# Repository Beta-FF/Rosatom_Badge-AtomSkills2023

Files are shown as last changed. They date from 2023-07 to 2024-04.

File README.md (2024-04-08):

# Rosatom Badge
Сувенирный значок с мастер-класса компетенции "Электроника" чемпионата AtomSkills 2023.  
[Ссылка на проект EasyEDA](https://oshwlab.com/treegervd/rosatom_badge_edapro)

Использованные библиотеки:
* [MicroCore](https://github.com/MCUdude/MicroCore) ([MCUdude](https://github.com/MCUdude))
* [ws2812b_attiny13](https://github.com/dsprenkels/ws2812b_attiny13) ([dsprenkels](https://github.com/dsprenkels))

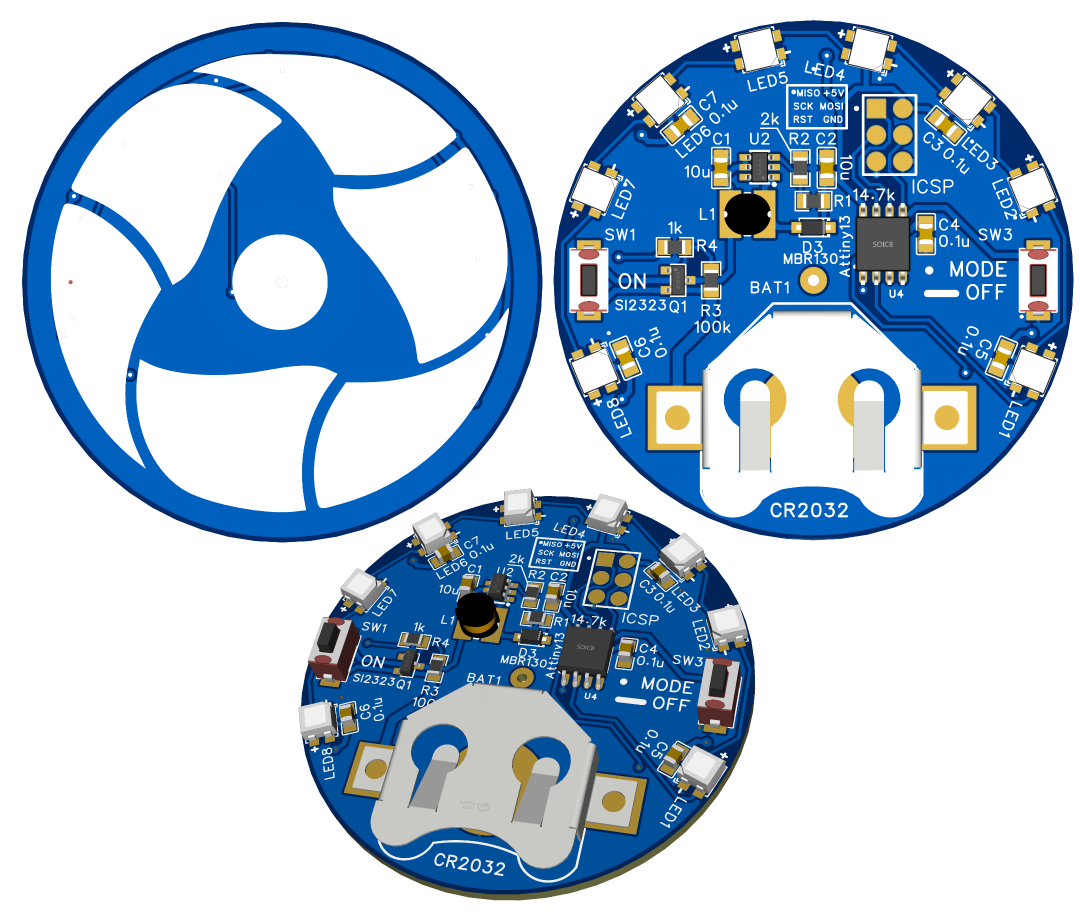
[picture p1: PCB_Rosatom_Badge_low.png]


## Подготовка
* Установить среду [Arduino IDE](https://www.arduino.cc/en/software) и ядро [MicroCore](https://github.com/MCUdude/MicroCore)
* Выбрать в настройках проекта:  
BOD: __BOD 2.7V__  
Bootloader: __No bootloader__  
Clock: __9.6 Mhz internal osc.__  
EEPROM: __EEPROM retained__  
* Если МК новый, то первую прошивку загружать на __slow__ скорости, например __USBasp slow__ (в зависимости от программатора). Дальнейшие загрузки возможны на нормальной скорости (__USBasp__).

## Функционал
Включение значка осуществляется кнопкой __ON__. Кратковременное нажатие кнопки __MODE/OFF__ циклически переключает режимы подсветки, а удержание более 1 сек. выключает значок.  

Режимы подсветки:
* Плавный перелив
* Бегущая точка 
* Статичный белый
* Бегущая радуга

## Техническая документация
[Attiny13 datasheet](http://ww1.microchip.com/downloads/en/DeviceDoc/doc2535.pdf)  
[WS2812B datasheet](https://cdn-shop.adafruit.com/datasheets/WS2812B.pdf)

## Известные баги
* значок не выключается при уровне BOD менее 2.7V. Связано с ошибкой в схеме самоблокировки питания. В выключенном состоянии на затворе Q1 присутствует напряжение ~1.7V, чего хватает для частичного открытия ключа.  
Для исправления нужно добавить еще один N-ch MOSFET или биполярный NPN от затвора Q1 на GND.  
Исправленная схема:  
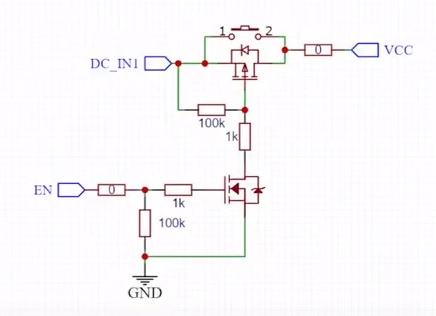
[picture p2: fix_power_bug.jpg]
  
* В редких случаях при установке батареи все светодиоды загораются ярким красным светом. Точная причина не опеределена. Возможно, поможет резистор на 100-500 Ом в разрыв цепи U4_PB3 - LED1_DIN.  
Лечится извлечением и повторной установкой батареи.  

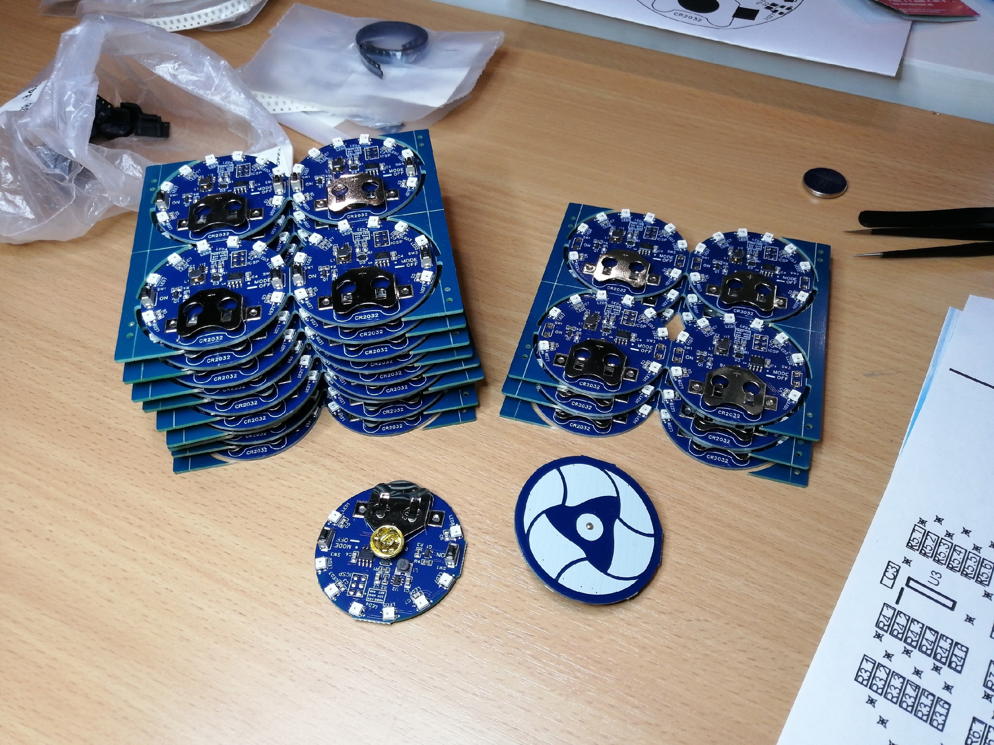
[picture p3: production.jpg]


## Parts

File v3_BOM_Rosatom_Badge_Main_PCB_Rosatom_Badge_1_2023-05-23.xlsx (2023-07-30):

No. | Quantity |  | Comment | Designator | Footprint | Link
1 | 200 | 1 | CR2032 | BAT1 | BAT-SMD_MYOUNG_MY-2032-04 | https://www.promelec.ru/product/340772/ | Замена на другой
2 | 400 | 2 | 10u | C1,C2 | C0805 | https://www.promelec.ru/product/112492/
3 | 1000 | 5 | 0.1u | C3,C4,C5,C6,C7 | C0805 | https://www.promelec.ru/product/124545/
4 | 200 | 1 | Any shottky diode | D3 | SOD-123FL_L2.6-W1.7-LS3.6-RD | https://www.promelec.ru/product/525329/
5 | 200 | 1 | 22u | L1 | IND-SMD_L4.5-W4.0_CD43 | https://www.promelec.ru/product/317110/ | Замена 22u на 10u
6 | 1800 | 9 | WS2812B-Mini | LED1,LED2,LED3,LED4,LED5,LED6,LED7,LED8,LED9 | LED-SMD_4P-L3.5-W3.5-TL_WS2812B | https://www.promelec.ru/product/352874/ | Меняем WS2812C-2020 на WS2812B-Mini
7 | 200 | 1 | SI2323 | Q1 | SOT-23-3_L2.9-W1.3-P1.90-LS2.4-BR | https://www.promelec.ru/product/526695/
8 | 200 | 1 | 14.7k | R1 | R0805 | https://www.promelec.ru/product/304878/
9 | 200 | 1 | 2k | R2 | R0805 | https://www.promelec.ru/product/109734/
10 | 200 | 1 | 100k | R3 | R0805 | https://www.promelec.ru/product/517703/
11 | 200 | 1 | 1k | R4 | R0805 | https://www.promelec.ru/product/517699/
12 | 400 | 2 | Switch SPST Button 0.05A 24VDC 1.77N SMD | SW1,SW2 | SW-SMD_L4.0-W3.0-LS5.0 | https://www.promelec.ru/product/358145/ | Замена на другую
13 | 200 | 1 | ATTINY13 | U4 | SOIC-8_L4.9-W3.9-P1.27-LS6.0-BL-2 | https://www.platan.ru/cgi-bin/qwery.pl/id=2015146753 | Замена ATTINY10 на ATTINY13
14 | 200 | 1 | MT3608 | U2 | SOT-23-6_L2.9-W1.6-P0.95-LS2.8-BR | https://www.chipdip.ru/product0/8020176720
15 | 200 | 1 |  | U3 | PROG_6PIN-2.54 | Площадки под прошивку (не компонент)
16 | 200 | 1 | Гвоздь латунный 0,9х12 |  | PAD | https://www.ozon.ru/product/gvozd-dekorativnyy-0-9-x-12-mm-15-sht-964737650/
17 | 200 | 1 | Основа для значка с цанговым зажимом |  |  | https://www.ozon.ru/product/osnova-dlya-znachka-s-tsangovym-zazhimom-20sht-tsvet-serebro-539947587/
18 | 1 |  | USB AVRISP XPII, программатор ISP |  |  | https://www.promelec.ru/product/325837/
19 | 40 |  | Элемент питания литиевый CR2032 |  |  | https://www.promelec.ru/product/402786/

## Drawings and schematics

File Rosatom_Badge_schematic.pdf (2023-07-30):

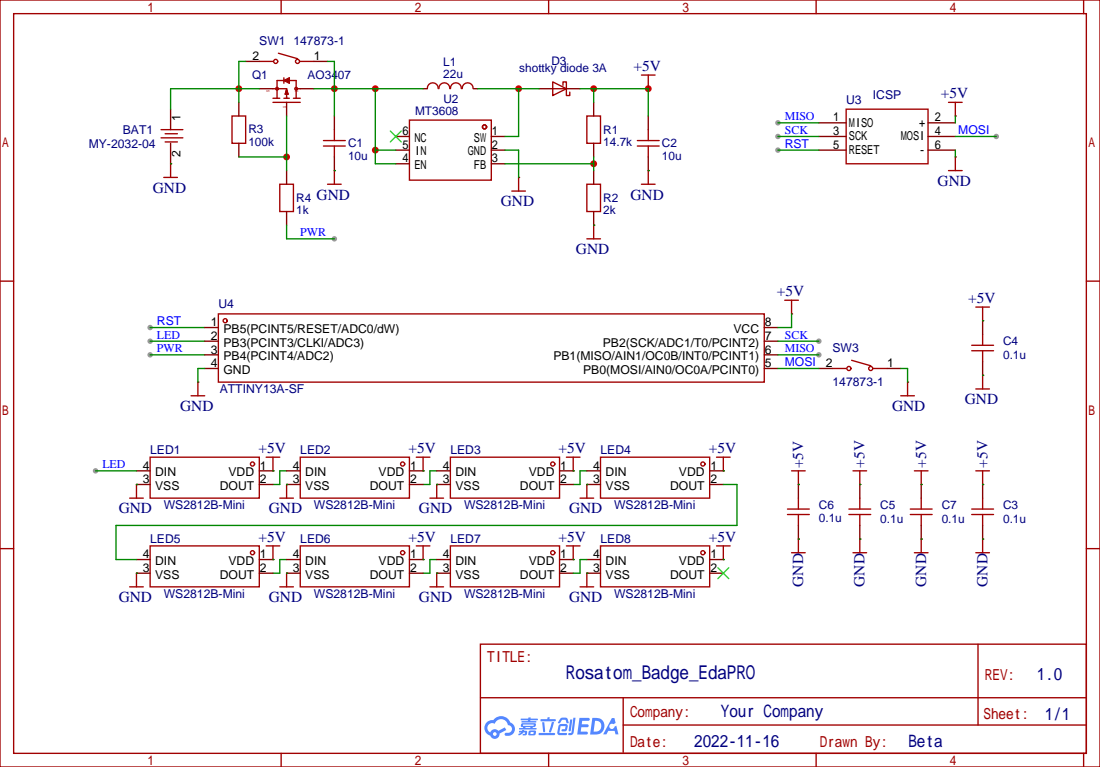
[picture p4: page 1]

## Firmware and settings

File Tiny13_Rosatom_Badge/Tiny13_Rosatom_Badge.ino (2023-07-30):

#include <util/delay.h>

#define STRIP_PIN   8     // пин ленты
#define NUMLEDS     8      // кол-во светодиодов
#define MOSFET_PIN  4//PB4
#define BTN_PIN     0//PB0

#define PRESS       0
#define NOT_PRESS   1

#define MAX_BRIGHT  10

#define STEP1   16
#define STEP2   2
#define TM      10
// 20 ~ 7mA max
// 10 ~ 3mA max
// 5  ~ 1.5mA max


uint8_t led_color[3 * (NUMLEDS - 1)];
uint8_t btn_old = NOT_PRESS;
uint8_t btn_hold = 0;
uint8_t mode = 0;
bool inc = true;
uint8_t dynamic_color = MAX_BRIGHT;
uint8_t dot_cnt = 0;
uint8_t timer_cnt = 0;
uint8_t color = 0;

void Wheel(byte WheelPos,uint8_t n);
void ws2812b_send_color_no_reset(const uint8_t pin_value, const uint8_t red, const uint8_t green, const uint8_t blue);

static void ws2812b_send_color(const uint8_t pin_value, const uint8_t red, const uint8_t green, const uint8_t blue) {
    DDRB |= pin_value;
    PORTB &= ~pin_value;
    _delay_us(50);
    ws2812b_send_color_no_reset(pin_value, red, green, blue);
}

void set_dot_ws2812(uint8_t position, uint8_t col_r, uint8_t col_g, uint8_t col_b) {
  if(position < NUMLEDS) {
        led_color[position * 3] = col_r;
        led_color[(position * 3) + 1] = col_g;
        led_color[(position * 3) + 2] = col_b;
  }
}

void set_full_ws2812(uint8_t col_r, uint8_t col_g, uint8_t col_b) {
    for(uint8_t i=0; i < NUMLEDS; i++) {
        led_color[i * 3] = col_r;
        led_color[(i * 3) + 1] = col_g;
        led_color[(i * 3) + 2] = col_b;
    }
}

void sync_ws2812() {
    ws2812b_send_color(STRIP_PIN, led_color[0], led_color[1], led_color[2]);
    for(uint8_t i=1; i<NUMLEDS; i++) {
        ws2812b_send_color_no_reset(STRIP_PIN, led_color[i * 3], led_color[(i * 3) + 1], led_color[(i * 3) + 2]);
    }
}

void mode_handler() {
    switch (mode) {
        case 0:
            set_full_ws2812(((dynamic_color >> 1) - (MAX_BRIGHT / 2)) * 2, (dynamic_color >> 1), MAX_BRIGHT);
            if(inc) dynamic_color++;
            else dynamic_color--;
            if(dynamic_color >= MAX_BRIGHT * 2) inc = false;
            if(dynamic_color <= MAX_BRIGHT)  inc = true;
            break;
        case 1:
            set_full_ws2812(0, MAX_BRIGHT * 0.5, MAX_BRIGHT);
            set_dot_ws2812(dot_cnt, MAX_BRIGHT * 0.7, MAX_BRIGHT * 0.7, MAX_BRIGHT * 0.7);
            set_dot_ws2812(dot_cnt + 1, MAX_BRIGHT * 0.7, MAX_BRIGHT * 0.7, MAX_BRIGHT * 0.7);
            if(timer_cnt == 0) {
                if(inc) dot_cnt++;
                else {
                    if(dot_cnt > 0) dot_cnt--;
                }
                if(dot_cnt >= NUMLEDS - 2) {
                    inc = false;
                    timer_cnt = 5;
                }
                if(dot_cnt == 0)  {
                    inc = true;
                    timer_cnt = 5;
                }
            }
            else timer_cnt--;
            break;
        case 2:
            set_full_ws2812(MAX_BRIGHT * 0.7, MAX_BRIGHT * 0.7, MAX_BRIGHT * 0.7);
            break;
        // case 3:
        //     set_full_ws2812(0, MAX_BRIGHT * 0.5, MAX_BRIGHT);
        //     break;
        case 3:
            for(int i=0; i< NUMLEDS; i++ ){
                Wheel(color + i*STEP1, i );    
                color += STEP2;
                delay(TM);
            }
            break;
    }
}

void button_press() {

}

void button_release() {
    if(++mode > 3) mode = 0;
}

void button_hold() {
    digitalWrite(MOSFET_PIN, HIGH);
}

void button_handler() {
    if(digitalRead(BTN_PIN) == PRESS) {
        if(btn_old == NOT_PRESS) button_press();
        btn_hold++;
        if(btn_hold >= 10) button_hold();
        btn_old = PRESS;
    } else {
        if(btn_old == PRESS) {
            if(btn_hold >= 10) ;//button_hold();
            else button_release();
            btn_hold = 0;
        }
        btn_old = NOT_PRESS;
    }
}

void setup() {
    pinMode(MOSFET_PIN, OUTPUT);
    digitalWrite(MOSFET_PIN, LOW);
    pinMode(BTN_PIN, INPUT_PULLUP);
    pinMode(3, OUTPUT);
}

void loop() {
    button_handler();
    mode_handler();
    sync_ws2812();
    delay(100);
}

// Input a value 0 to 255 to get a color value.
// The colours are a transition r - g - b - back to r.
void Wheel(byte WheelPos,uint8_t n) {
  if(WheelPos < 85) {
     led_color[n * 3] = MAX_BRIGHT * (WheelPos * 3) / 255;
     led_color[n * 3 + 1] = MAX_BRIGHT * (255 - WheelPos * 3) / 255;
     led_color[n * 3 + 2] = 0;
  } 
  else if(WheelPos < 170) {
     WheelPos -= 85;
     led_color[n * 3] = MAX_BRIGHT * (255 - WheelPos * 3) / 255;
     led_color[n * 3 + 1] = 0;
     led_color[n * 3 + 2] = MAX_BRIGHT * (WheelPos * 3) / 255;
  } 
  else {
     WheelPos -= 170;
     led_color[n * 3] = 0;
     led_color[n * 3 + 1] = MAX_BRIGHT * (WheelPos * 3) / 255;
     led_color[n * 3 + 2] = MAX_BRIGHT * (255 - WheelPos * 3) / 255;
  }
}

void ws2812b_send_color_no_reset(const uint8_t pin_value, const uint8_t red, const uint8_t green, const uint8_t blue) {
    DDRB |= pin_value;
    const uint8_t portb = PORTB; // PORTB is volatile, so preload value
    const uint8_t lo = portb & ~pin_value;
    const uint8_t hi = portb | pin_value;
    __asm__  volatile (   
                // Each 12 cycles go high on cycle 0 and go low on cycle:
                //   - 8 if a one bit is transmitted
                //   - 4 if a zero bit is transmitted
                //
                // In the spare time we have left, we read out the next bit from the current color
                // byte. We keep a mask bit in r17, do a bitwise and operation, and branch if (not)
                // zero. After 8 shifts the carry flag will be set and we will move on to the next
                // color bit.
                //
                // I have figured that it should be possible to decode the bits from the RGB values
                // on the fly. However, I think that we do not have enough cycles to read from the
                // different color in a non-unrolled loop, but to be completely honest I did not
                // take a lot of effort to find a good argument on why this should be impossible.
                //
                ".green:                        \n\t"
                "mov r16,%[green]               \n\t"
                "ldi r17,0x80                   \n\t"
                "and r16,r17                    \n\t"
                "brne .green_transmit_one_0     \n\t"
                "rjmp .green_transmit_zero_0    \n\t"
                
                // Green
                ".green_transmit_one_1:         \n\t"
                "nop                            \n\t" // cycle -1
                ".green_transmit_one_0:         \n\t"
                "out 0x18,%[hi]                 \n\t" // cycle 0
                "nop                            \n\t" // cycle 1
                "lsr r17                        \n\t" // cycle 2
                "brcs .green_transmit_one_done  \n\t" // cycle 3
                "rjmp .+0                       \n\t" // cycle 4
                "mov r16,%[green]               \n\t" // cycle 6
                "and r16,r17                    \n\t" // cycle 7
                "out 0x18,%[lo]                 \n\t" // cycle 8
                "brne .green_transmit_one_1     \n\t" // cycle 9
                "rjmp .green_transmit_zero_0    \n\t" // cycle 10
                
                ".green_transmit_one_done:      \n\t"
                "ldi r17,0x80                   \n\t" // cycle 5
                "mov r16,%[red]                 \n\t" // cycle 6
                "and r16,r17                    \n\t" // cycle 7
                "out 0x18,%[lo]                 \n\t" // cycle 8
                "brne .red_transmit_one_1       \n\t" // cycle 9
                "rjmp .red_transmit_zero_0      \n\t" // cycle 10
                
                ".green_transmit_zero_0:        \n\t"
                "out 0x18,%[hi]                 \n\t" // cycle 0
                "lsr r17                        \n\t" // cycle 1
                "brcs .green_transmit_zero_done \n\t" // cycle 2
                "nop                            \n\t" // cycle 3
                "out 0x18,%[lo]                 \n\t" // cycle 4
                "rjmp .+0                       \n\t" // cycle 5
                "mov r16,%[green]               \n\t" // cycle 7
                "and r16,r17                    \n\t" // cycle 8
                "brne .green_transmit_one_1     \n\t" // cycle 9
                "rjmp .green_transmit_zero_0    \n\t" // cycle 10
                
                ".green_transmit_zero_done:     \n\t"
                "out 0x18,%[lo]                 \n\t" // cycle 4
                "nop                            \n\t" // cycle 5
                "ldi r17,0x80                   \n\t" // cycle 6
                "mov r16,%[red]                 \n\t" // cycle 7
                "and r16,r17                    \n\t" // cycle 8
                "brne .red_transmit_one_1       \n\t" // cycle 9
                "rjmp .red_transmit_zero_0      \n\t" // cycle 10
                
                // Red
                ".red_transmit_one_1:           \n\t"
                "nop                            \n\t" // cycle -1
                ".red_transmit_one_0:           \n\t"
                "out 0x18,%[hi]                 \n\t" // cycle 0
                "nop                            \n\t" // cycle 1
                "lsr r17                        \n\t" // cycle 2
                "brcs .red_transmit_one_done    \n\t" // cycle 3
                "rjmp .+0                       \n\t" // cycle 4
                "mov r16,%[red]                 \n\t" // cycle 6
                "and r16,r17                    \n\t" // cycle 7
                "out 0x18,%[lo]                 \n\t" // cycle 8
                "brne .red_transmit_one_1       \n\t" // cycle 9
                "rjmp .red_transmit_zero_0      \n\t" // cycle 10
                
                ".red_transmit_one_done:        \n\t"
                "ldi r17,0x80                   \n\t" // cycle 5
                "mov r16,%[blue]                \n\t" // cycle 6
                "and r16,r17                    \n\t" // cycle 7
                "out 0x18,%[lo]                 \n\t" // cycle 8
                "brne .blue_transmit_one_1      \n\t" // cycle 9
                "rjmp .blue_transmit_zero_0     \n\t" // cycle 10
                
                ".red_transmit_zero_0:          \n\t"
                "out 0x18,%[hi]                 \n\t" // cycle 0
                "lsr r17                        \n\t" // cycle 1
                "brcs .red_transmit_zero_done   \n\t" // cycle 2
                "nop                            \n\t" // cycle 3
                "out 0x18,%[lo]                 \n\t" // cycle 4
                "rjmp .+0                       \n\t" // cycle 5
                "mov r16,%[red]                 \n\t" // cycle 7
                "and r16,r17                    \n\t" // cycle 8
                "brne .red_transmit_one_1       \n\t" // cycle 9
                "rjmp .red_transmit_zero_0      \n\t" // cycle 10
                
                ".red_transmit_zero_done:       \n\t"
                "out 0x18,%[lo]                 \n\t" // cycle 4
                "nop                            \n\t" // cycle 5
                "ldi r17,0x80                   \n\t" // cycle 6
                "mov r16,%[blue]                \n\t" // cycle 7
                "and r16,r17                    \n\t" // cycle 8
                "brne .blue_transmit_one_1      \n\t" // cycle 9
                "rjmp .blue_transmit_zero_0     \n\t" // cycle 10
                
                // Blue
                ".blue_transmit_one_1:          \n\t"
                "nop                            \n\t" // cycle -1
                ".blue_transmit_one_0:          \n\t"
                "out 0x18,%[hi]                 \n\t" // cycle 0
                "rjmp .+0                       \n\t" // cycle 1
                "lsr r17                        \n\t" // cycle 3
                "brcs .blue_transmit_one_done   \n\t" // cycle 4
                "nop                            \n\t" // cycle 5
                "mov r16,%[blue]                \n\t" // cycle 6
                "and r16,r17                    \n\t" // cycle 7
                "out 0x18,%[lo]                 \n\t" // cycle 8
                "brne .blue_transmit_one_1      \n\t" // cycle 9
                "rjmp .blue_transmit_zero_0     \n\t" // cycle 10
                
                ".blue_transmit_one_done:       \n\t"
                "rjmp .blue_transmit_zero_done  \n\t" // cycle 6
                
                ".blue_transmit_zero_0:         \n\t"
                "out 0x18,%[hi]                 \n\t" // cycle 0
                "lsr r17                        \n\t" // cycle 1
                "brcs .blue_transmit_zero_done  \n\t" // cycle 2
                "nop                            \n\t" // cycle 3
                "out 0x18,%[lo]                 \n\t" // cycle 4
                "rjmp .+0                       \n\t" // cycle 5
                "mov r16,%[blue]                \n\t" // cycle 7
                "and r16,r17                    \n\t" // cycle 8
                "brne .blue_transmit_one_1      \n\t" // cycle 9
                "rjmp .blue_transmit_zero_0     \n\t" // cycle 10
                
                ".blue_transmit_zero_done:      \n\t"
                "out 0x18,%[lo]                 \n\t" // cycle 4 / cycle 8
                ".end:                          \n\t"
            
            : // No outputs
            : [lo] "r" (lo), [hi] "r" (hi), [green] "r" (green), [red] "r" (red), [blue] "r" (blue)
            : "r16", "r17"
    );
}

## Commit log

2023-07-30 Rosatom_Badge
    Rosatom_Badge
    [Drill_PTH_Through.DRL, Drill_PTH_Through_Via.DRL, Gerber_BoardOutlineLayer.GKO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]
2023-08-01 fix строк
